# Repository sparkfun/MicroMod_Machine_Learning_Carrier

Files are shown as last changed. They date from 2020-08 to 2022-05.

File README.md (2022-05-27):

SparkFun MicroMod Machine Learning Carrier Board
========================================

SparkFun MicroMod Machine Learning Carrier Board

[*SparkFun MicroMod Machine Learning Carrier Board (16400)*](https://www.sparkfun.com/products/16400)

The MicroMod Machine Learning Carrier Board combines some of the features of our SparkFun Edge Board and SparkFun Artemis boards, but allows you the freedom to explore with any processor in the MicroMod lineup without the need for a central computer or web connection. Voice recognition, always-on voice commands, gesture, or image recognition are possible with TensorFlow applications. The cloud is impressively powerful but all-the-time connection requires power and connectivity that may not be available. Edge computing handles discrete tasks such as determining if someone said "yes" and responds accordingly. The audio analysis is done on the MicroMod combination rather than on the web. This dramatically reduces costs and complexity while limiting potential data privacy leaks. 

This board features two MEMS microphones with an operational amplifier, an ST LIS2DH12 3-axis accelerometer on its own I<sup>2</sup>C bus, a connector to interface to an OV7670 camera (sold separately), and Qwiic connector. A modern USB-C connector makes programming easy and we've exposed the JTAG connector for more advanced users who prefer to use the power and speed of professional tools. We've even added a convenient jumper to measure current consumption for low power testing.

Repository Contents
-------------------

* **/Documentation** - Data sheets, additional product information
* **/Hardware** - Eagle design files (.brd, .sch)
* **/Libraries** - Libraries for use with the <PRODUCT NAME>

Documentation
--------------
* **[Hookup Guide](https://learn.sparkfun.com/tutorials/micromod-machine-learning-carrier-board-hookup-guide)** - Basic hookup guide for the SparkFun MicroMod Machine Learning Carrier Board.
* **[Getting Started with MicroMod](https://learn.sparkfun.com/tutorials/getting-started-with-micromod)** - A tutorial to help you get started with the MicroMod Ecosystem. 
* **[Designing with MicroMod](https://learn.sparkfun.com/tutorials/designing-with-micromod)** - A tutorial to walk you through the specs of the MicroMod processor and carrier board as well as the basics of incorporating the MicroMod form factor into your own PCB designs.

License Information
-------------------

This product is _**open source**_! 

Please review the LICENSE.md file for license information. 

If you have any questions or concerns on licensing, please contact technical support on our [SparkFun forums](https://forum.sparkfun.com/viewforum.php?f=152).

Distributed as-is; no warranty is given.

- Your friends at SparkFun.

_<COLLABORATION CREDIT>_

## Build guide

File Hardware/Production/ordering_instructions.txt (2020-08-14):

panel size, 139x165mm
PCB thickness, 1.6mm
number of layers, 2
soldermask color, Red
silkscreen color, White
oz copper, 1oz
finish, HASL lead free
stencils, none
pcs per panel, 6
min trace width, 0.1778mm / 0.0070in
min drill size, 0.3048mm / 0.0120in

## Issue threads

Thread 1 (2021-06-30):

Example1_MicrophoneOutput compile error

johncaipa, 2021-06-30:
Hi I am trying to test this example of the microphone, but I have the following error:

> Arduino:1.8.13 (Windows 10), Tarjeta:"SparkFun MicroMod nRF52840 Processor Board"
Example1_MicrophoneOutput:24:1: error: 'AP3_PDM' does not name a type; did you mean 'NRF_PDM'?
 AP3_PDM myPDM;   //Create instance of PDM class
 ^~~~~~~
 NRF_PDM
D:MicroMod_Machine_Learning_Carrier-master\Examples\Example1_MicrophoneOutput\Example1_MicrophoneOutput.ino: In function 'void setup()':
Example1_MicrophoneOutput:35:7: error: 'myPDM' was not declared in this scope
   if (myPDM.begin(36, 37) == false) // Turn on PDM with default settings, start interrupts
       ^~~~~
D:MicroMod_Machine_Learning_Carrier-master\Examples\Example1_MicrophoneOutput\Example1_MicrophoneOutput.ino:35:7: note: suggested alternative: 'PDM'
   if (myPDM.begin(36, 37) == false) // Turn on PDM with default settings, start interrupts
       ^~~~~
       PDM
D:MicroMod_Machine_Learning_Carrier-master\Examples\Example1_MicrophoneOutput\Example1_MicrophoneOutput.ino: In function 'void loop()':
Example1_MicrophoneOutput:48:7: error: 'myPDM' was not declared in this scope
   if (myPDM.available())
       ^~~~~
D:MicroMod_Machine_Learning_Carrier-master\Examples\Example1_MicrophoneOutput\Example1_MicrophoneOutput.ino:48:7: note: suggested alternative: 'PDM'
   if (myPDM.available())
       ^~~~~
       PDM
Example1_MicrophoneOutput:56:24: error: 'AM_HAL_SYSCTRL_SLEEP_DEEP' was not declared in this scope
   am_hal_sysctrl_sleep(AM_HAL_SYSCTRL_SLEEP_DEEP);
                        ^~~~~~~~~~~~~~~~~~~~~~~~~
Example1_MicrophoneOutput:56:3: error: 'am_hal_sysctrl_sleep' was not declared in this scope
   am_hal_sysctrl_sleep(AM_HAL_SYSCTRL_SLEEP_DEEP);
   ^~~~~~~~~~~~~~~~~~~~
D:MicroMod_Machine_Learning_Carrier-master\Examples\Example1_MicrophoneOutput\Example1_MicrophoneOutput.ino: In function 'void printPDMConfig()':
Example1_MicrophoneOutput:139:11: error: 'myPDM' was not declared in this scope
   switch (myPDM.getClockDivider())
           ^~~~~
....

exit status 1
'AP3_PDM' does not name a type; did you mean 'NRF_PDM'?

johncaipa, 2021-06-30:
Could you help me, I don't know what the problem is, I want to be able to use the microphone for my tinyml models

santaimpersonator, 2021-07-01:
It looks like you have the nRF processor board selected.

The example explicitly states that it is intended for the Artemis processor board:
>[This example demonstrates how to use the pulse density microphone (PDM) on Artemis boards.
> This library and example are heavily based on the Apollo3 pdm_fft example.](https://github.com/sparkfun/MicroMod_Machine_Learning_Carrier/blob/master/Examples/Example1_MicrophoneOutput/Example1_MicrophoneOutput.ino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)

johncaipa, 2021-07-01:
ok I understand, my mistake, but could there be some examples of how to use the sensors of these boards:  MicroMod nRF52840 Processor Board + MicroMod Machine Learning Board, especially to use the microphone.

santaimpersonator, 2021-07-01:
Unfortunately, the nRF processor board was released after the ML carrier board. Therefore, I don't know if any of the examples associated with this carrier board will work for that MicroMod combination.

However, there was an edge impulse workshop from yesterday that might be helpful to you: https://www.youtube.com/watch?v=qdzPTzL7ChI

Since this is not an actual issue with the board, I am going to close this issue. Feel free to use [our forum for further technical assistance](https://forum.sparkfun.com/).

Closed 2021-07-01.

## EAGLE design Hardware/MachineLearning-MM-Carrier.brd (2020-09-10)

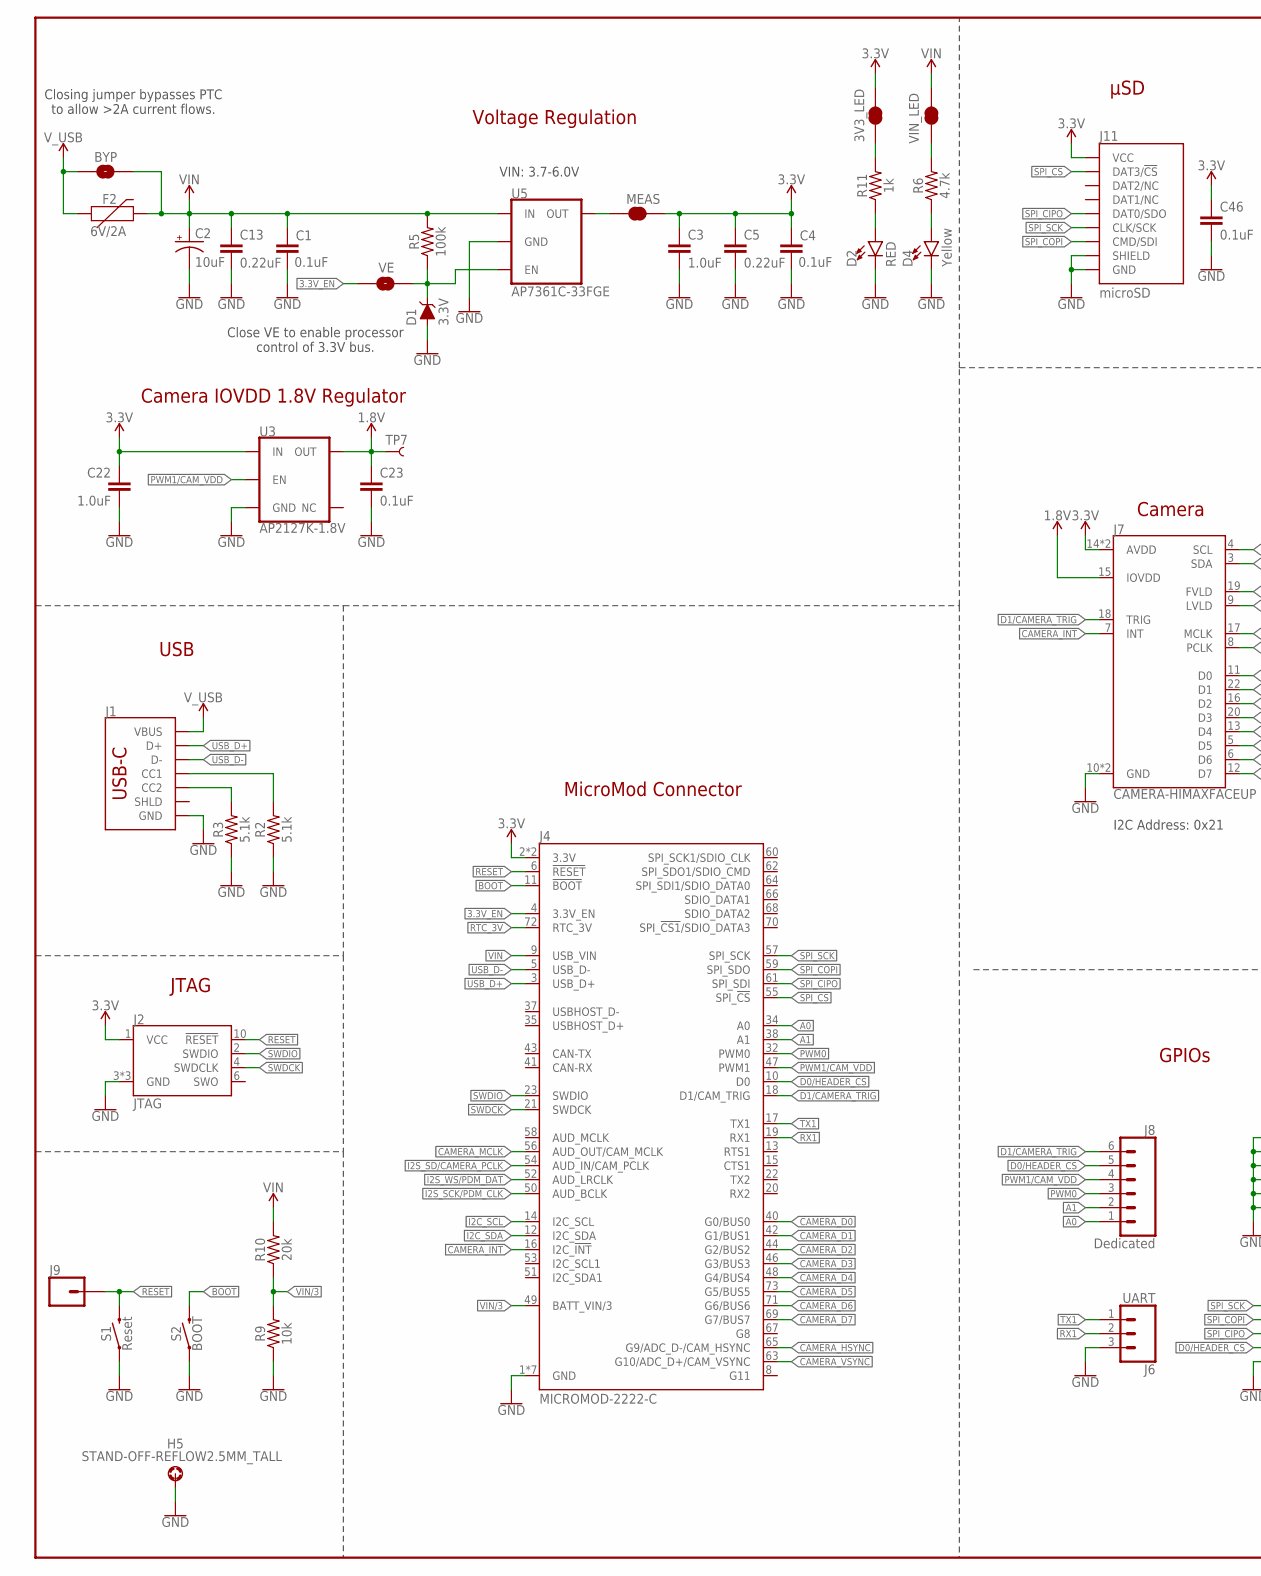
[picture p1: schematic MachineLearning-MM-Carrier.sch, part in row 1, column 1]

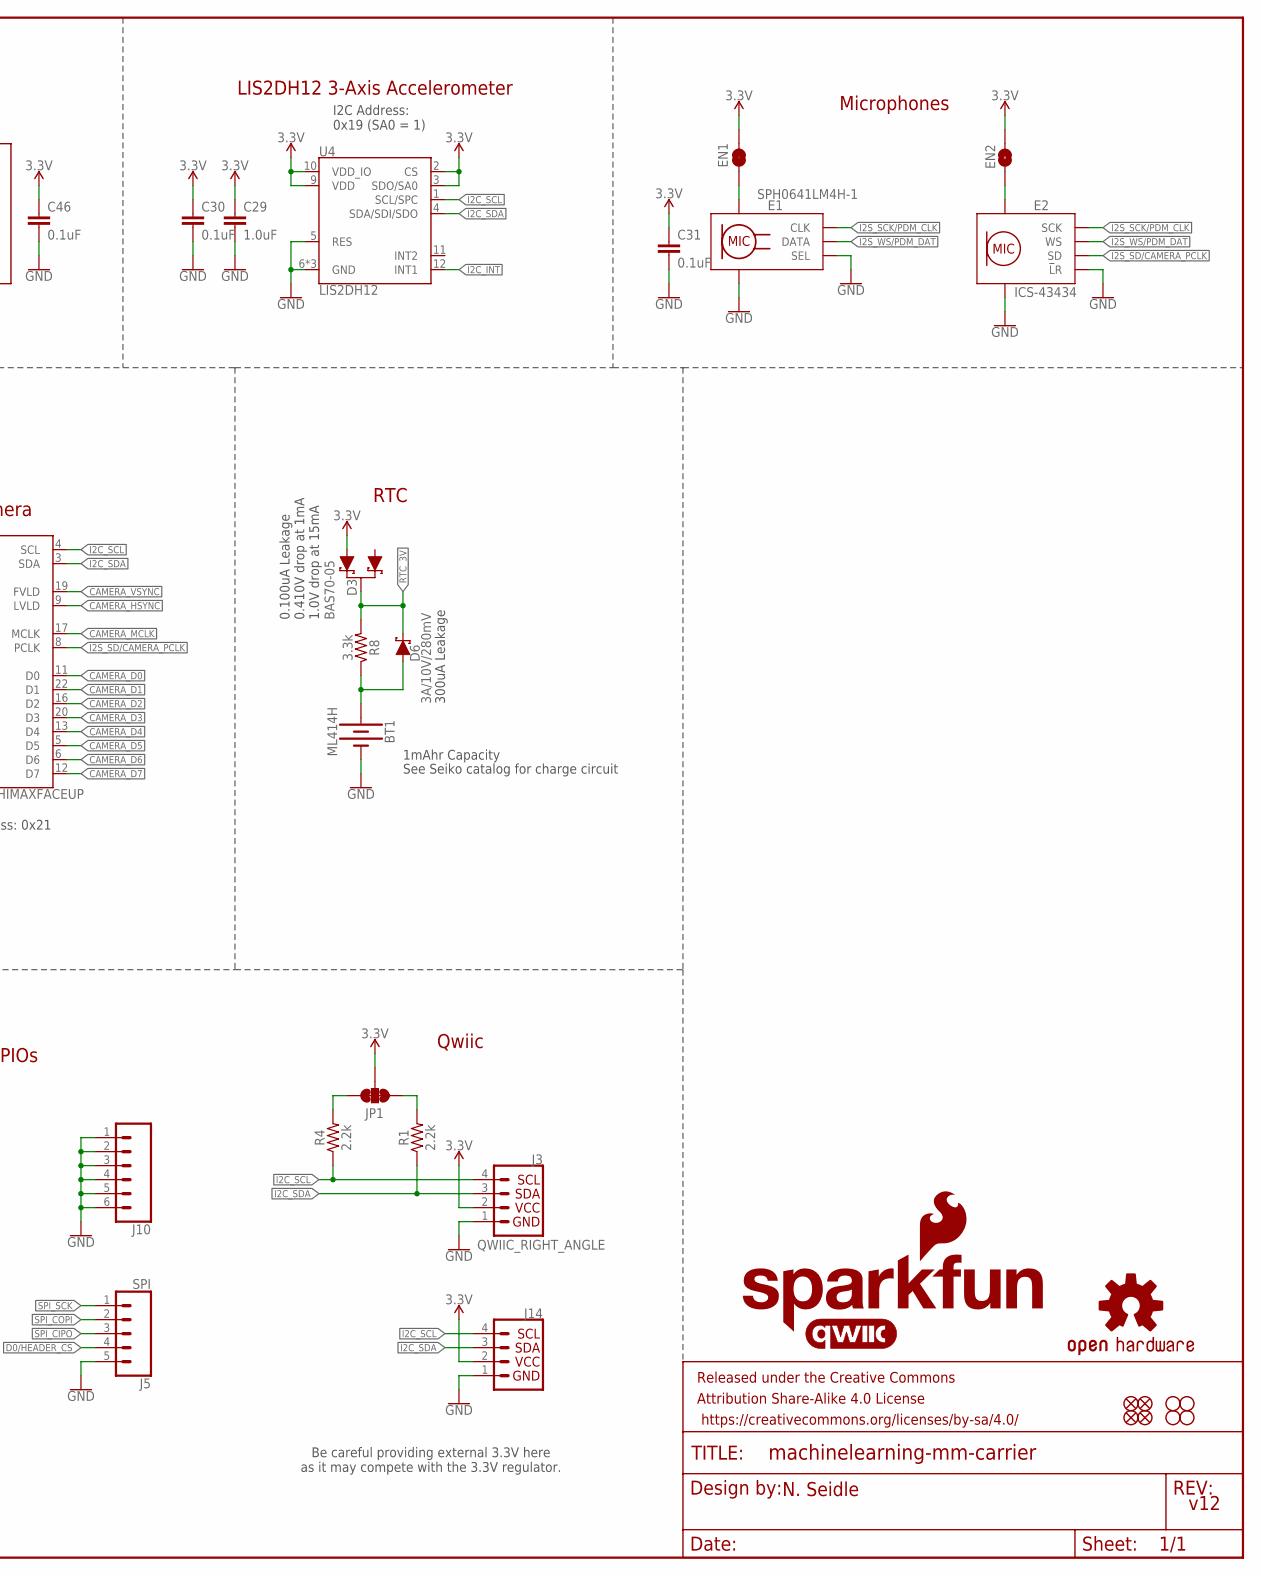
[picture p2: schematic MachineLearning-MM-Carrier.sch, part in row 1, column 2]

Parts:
3V3_LED: JUMPER-SMT_2_NC_TRACE_SILK; SMT-JUMPER_2_NC_TRACE_SILK
BT1: ML414H; ML414H_IV01E
BYP: JUMPER-SMT_2_NO_SILK; SMT-JUMPER_2_NO_SILK
C1, C4, C23, C30, C31, C46: 0.1uF; 0603
C2: 10uF; EIA3216
C3, C22, C29: 1.0uF; 0603
C5, C13: 0.22uF; 0603
D1: 3.3V; SOD-323
D2: RED; LED-0603
D3: BAS70-05; SOT23-3
D4: Yellow; LED-0603
D6: 3A/10V/280mV; SOD-323
E1: SPH0641LM4H-1; SPH0641LM4H-1_MICROPHONE
E2: ICS-43434
EN1: JUMPER-SMT_2_NC_TRACE_SILK; SMT-JUMPER_2_NC_TRACE_SILK
EN2: JUMPER-SMT_2_NO_SILK; SMT-JUMPER_2_NO_SILK
F2: 6V/2A; 1210
FD1, FD2, FD3, FD4: FIDUCIALUFIDUCIAL; FIDUCIAL-MICRO
FRAME1: FRAME-LEDGER; CREATIVE_COMMONS
H1, H2, H3, H4: STAND-OFF
H5: STAND-OFF-REFLOW2.5MM_TALL; STAND-OFF-REFLOW-M2.5
J1: USB_C_2-LAYER_PADS; USB-C-16P-2LAYER-PADS
J2: JTAG; 2X5-PTH-1.27MM
J3: QWIIC_RIGHT_ANGLE; JST04_1MM_RA
J4: MICROMOD-2222-C; M.2-CONNECTOR-E
J5: SPI; 1X05_NO_SILK
J6: UART; 1X03_NO_SILK
J7: CAMERA-HIMAXFACEUP; FPC05024-42201
J8: Dedicated; 1X06_NO_SILK
J9: CONN_01PTH_NO_SILK_YES_STOP; 1X01_NO_SILK
J10: CONN_06NO_SILK_NO_POP; 1X06_NO_SILK
J11: microSD; MICRO-SD-SOCKET
J14: I2C_STANDARD_NO_SILK; 1X04_NO_SILK
JP1: JUMPER-SMT_3_2-NC_TRACE_SILK; SMT-JUMPER_3_2-NC_TRACE_SILK
LOGO1: SFE_LOGO_NAME_FLAME.1_INCH; SFE_LOGO_NAME_FLAME_.1
LOGO2: QWIIC_LOGO_CONNECTOR; QWIIC_5.5MM
LOGO3: OSHW-LOGOMINI; OSHW-LOGO-MINI
MEAS: JUMPER-COMBO_2_NC_TRACE; COMBO-JUMPER_2_NC_TRACE
R1, R4: 2.2k; 0603
R2, R3: 5.1k; 0603
R5: 100k; 0603
R6: 4.7k; 0603
R8: 3.3k; 0603
R9: 10k; 0603
R10: 20k; 0603
R11: 1k; 0603
S1: Reset; TACTILE_SWITCH_SMD_5.2MM
S2: BOOT; TACTILE_SWITCH_SMD_5.2MM
TP7: TEST-POINT3X5; PAD.03X.05
U3: AP2127K-1.8V; SOT23-5
U4: LIS2DH12; LGA-12-LISDH12
U5: AP7361C-33FGE; UDFN-8
VE: JUMPER-SMT_2_NO_SILK; SMT-JUMPER_2_NO_SILK
VIN_LED: JUMPER-SMT_2_NC_TRACE_SILK; SMT-JUMPER_2_NC_TRACE_SILK

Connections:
1.8V: C23.1, J7.15 (IOVDD), TP7.P$1, U3.5 (OUT)
3.3V: 3V3_LED.2, C3.1, C4.1, C5.1, C22.1, C29.1, C30.1, C31.1, C46.1, D3.2 (A1), EN1.2, EN2.2, J2.1 (VCC), J3.2, J4.2 (3.3V), J4.74 (3.3V), J7.14 (AVDD), J7.21 (AVDD), J11.VCC, J14.2, JP1.2, MEAS.2, MEAS.4 (2), U3.1 (IN), U4.2 (CS), U4.3 (SDO/SA0), U4.9 (VDD), U4.10 (VDD_IO)
3.3V_EN: J4.4 (3.3V_EN), VE.1
!BOOT!: J4.11 (!BOOT!), S2.3 (2), S2.4 (2)
!RESET!: J2.10 (!RESET), J4.6 (!RESET!), J9.1, S1.3 (2), S1.4 (2)
A0: J4.34 (A0), J8.1
A1: J4.38 (A1), J8.2
CAMERA_D0: J4.40 (G0/BUS0), J7.11 (D0)
CAMERA_D1: J4.42 (G1/BUS1), J7.22 (D1)
CAMERA_D2: J4.44 (G2/BUS2), J7.16 (D2)
CAMERA_D3: J4.46 (G3/BUS3), J7.20 (D3)
CAMERA_D4: J4.48 (G4/BUS4), J7.13 (D4)
CAMERA_D5: J4.73 (G5/BUS5), J7.5 (D5)
CAMERA_D6: J4.71 (G6/BUS6), J7.6 (D6)
CAMERA_D7: J4.69 (G7/BUS7), J7.12 (D7)
CAMERA_HSYNC: J4.65 (G9/ADC_D-/CAM_HSYNC), J7.9 (LVLD)
CAMERA_INT: J4.16 (I2C_!INT!), J7.7 (INT)
CAMERA_MCLK: J4.56 (AUD_OUT/CAM_MCLK), J7.17 (MCLK)
CAMERA_VSYNC: J4.63 (G10/ADC_D+/CAM_VSYNC), J7.19 (FVLD)
D0/HEADER_!CS!: J4.10 (D0), J5.4, J8.5
D1/CAMERA_TRIG: J4.18 (D1/CAM_TRIG), J7.18 (TRIG), J8.6
GND: BT1.-, C1.2, C2.-, C3.2, C4.2, C5.2, C13.2, C22.2, C23.2, C29.2, C30.2, C31.2, C46.2, D1.A, D2.C, D4.C, E1.2 (SEL), E1.3 (GND), E1.6 (GND), E1.7 (GND), E1.8 (GND), E2.2 (!L!R), E2.3 (GND), E2.7 (GND), E2.8 (GND), E2.9 (GND), H5.1, J1.GND, J1.GND2 (GND), J2.3 (GND), J2.5 (GND), J2.9 (GND), J3.1, J4.1 (GND), J4.7 (GND), J4.33 (GND), J4.36 (GND), J4.39 (GND), J4.45 (GND), J4.75 (GND), J5.5, J6.3, J7.10 (GND), J7.23 (GND), J10.1, J10.2, J10.3, J10.4, J10.5, J10.6, J11.CD1 (SHIELD), J11.GND, J11.GND1 (GND), J11.GND3 (GND), J14.1, R2.1, R3.1, R9.1, S1.1, S1.2 (1), S2.1, S2.2 (1), U3.2 (GND), U4.5 (RES), U4.6 (GND), U4.7 (GND), U4.8 (GND), U5.4 (GND), U5.EP (GND)
I2C_!INT!: U4.12 (INT1)
I2C_SCL: J3.4, J4.14 (I2C_SCL), J7.4 (SCL), J14.4, R4.1, U4.1 (SCL/SPC)
I2C_SDA: J3.3, J4.12 (I2C_SDA), J7.3 (SDA), J14.3, R1.1, U4.4 (SDA/SDI/SDO)
I2S_SCK/PDM_CLK: E1.4 (CLK), E2.4 (SCK), J4.50 (AUD_BCLK)
I2S_SD/CAMERA_PCLK: E2.6 (SD), J4.54 (AUD_IN/CAM_PCLK), J7.8 (PCLK)
I2S_WS/PDM_DAT: E1.1 (DATA), E2.1 (WS), J4.52 (AUD_LRCLK)
unnamed: R6.2, VIN_LED.1
unnamed: JP1.3, R4.2
unnamed: JP1.1, R1.2
unnamed: E1.5 (VDD), EN1.1
unnamed: E2.5 (VDD), EN2.1
unnamed: 3V3_LED.1, R11.2
unnamed: D2.A, R11.1
unnamed: D4.A, R6.1
unnamed: J1.A5 (CC1), R2.2
unnamed: J1.B5 (CC2), R3.2
unnamed: D1.C, R5.1, U5.5 (EN), VE.2
unnamed: BT1.+, D6.A, R8.1
PWM0: J4.32 (PWM0), J8.3
PWM1/CAM_VDD: J4.47 (PWM1), J8.4, U3.3 (EN)
RTC_3V: D3.3 (C), D6.C, J4.72 (RTC_3V), R8.2
RX1: J4.19 (RX1), J6.2
SPI_!CS!: J4.55 (SPI_!CS!), J11.CS/DAT3 (DAT3/!CS!)
SPI_CIPO: J4.61 (SPI_SDI), J5.3, J11.DO/DAT0 (DAT0/SDO)
SPI_COPI: J4.59 (SPI_SDO), J5.2, J11.DI/CMD (CMD/SDI)
SPI_SCK: J4.57 (SPI_SCK), J5.1, J11.SCLK (CLK/SCK)
SWDCK: J2.4 (SWDCLK), J4.21 (SWDCK)
SWDIO: J2.2 (SWDIO), J4.23 (SWDIO)
TX1: J4.17 (TX1), J6.1
USB_D+: J1.A6 (D+), J1.B6 (D+), J4.3 (USB_D+)
USB_D-: J1.A7 (D-), J1.B7 (D-), J4.5 (USB_D-)
VIN: BYP.2, C1.1, C2.+, C13.1, F2.2, J4.9 (USB_VIN), R5.2, R10.2, U5.8 (IN), VIN_LED.2
VIN/3: J4.49 (BATT_VIN/3), R9.2, R10.1
VREG_3.3V: MEAS.1, MEAS.3 (1), U5.1 (OUT)
V_USB: BYP.1, F2.1, J1.VBUS1 (VBUS), J1.VBUS2 (VBUS)

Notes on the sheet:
LIS2DH12 3-Axis Accelerometer
I2C Address: 0x19 (SA0 = 1)
I2C Address: 0x21
μSD
300uA Leakage
See Seiko catalog for charge circuit
1mAhr Capacity
Closing jumper bypasses PTC to allow >2A current flows.
JTAG
Camera IOVDD 1.8V Regulator
USB
GPIOs
Camera
Microphones
Qwiic
RTC
Voltage Regulation
MicroMod Connector
0.100uA Leakage 0.410V drop at 1mA 1.0V drop at 15mA
N. Seidle
v12
VIN: 3.7-6.0V
Be careful providing external 3.3V here as it may compete with the 3.3V regulator.
Close VE to enable processor control of 3.3V bus.

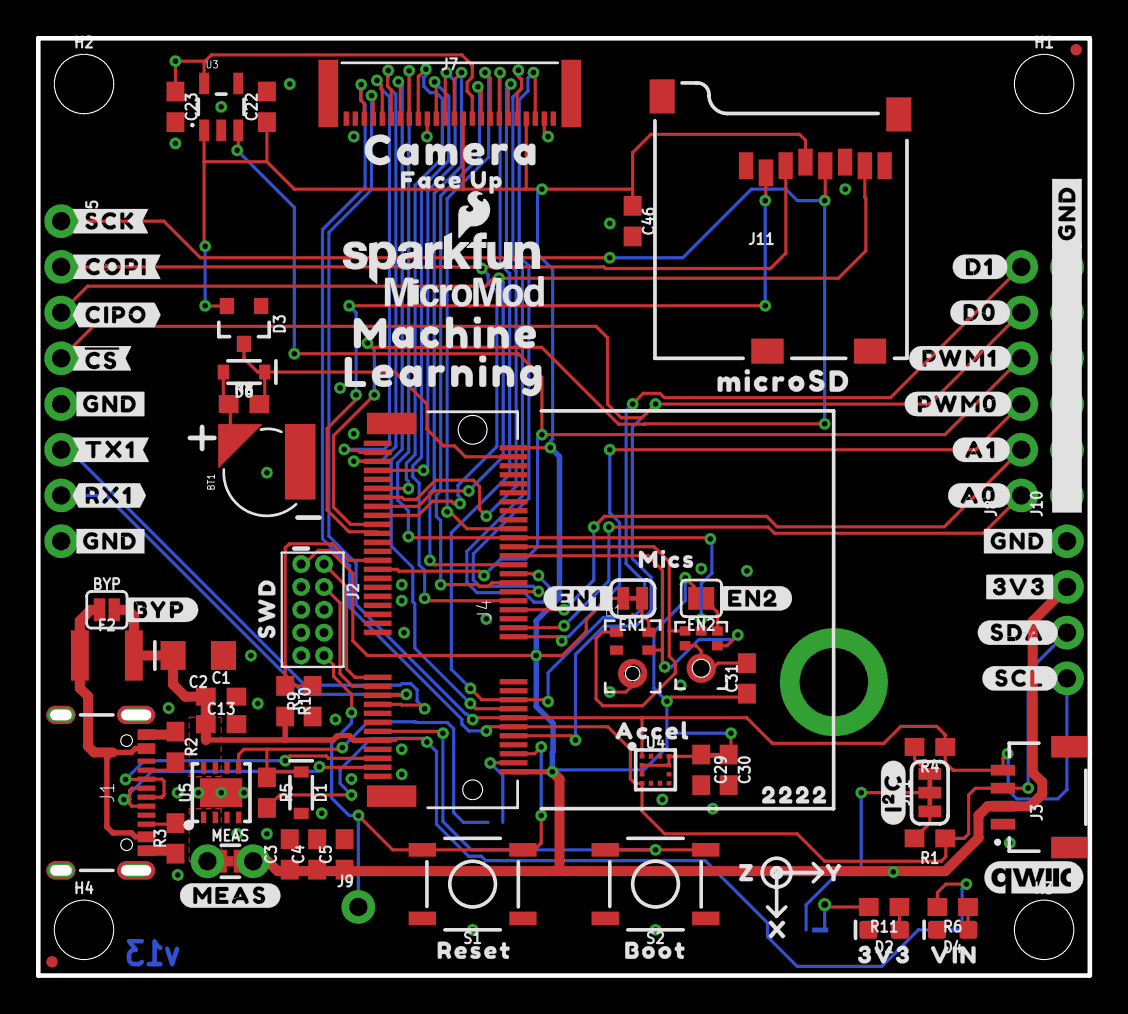
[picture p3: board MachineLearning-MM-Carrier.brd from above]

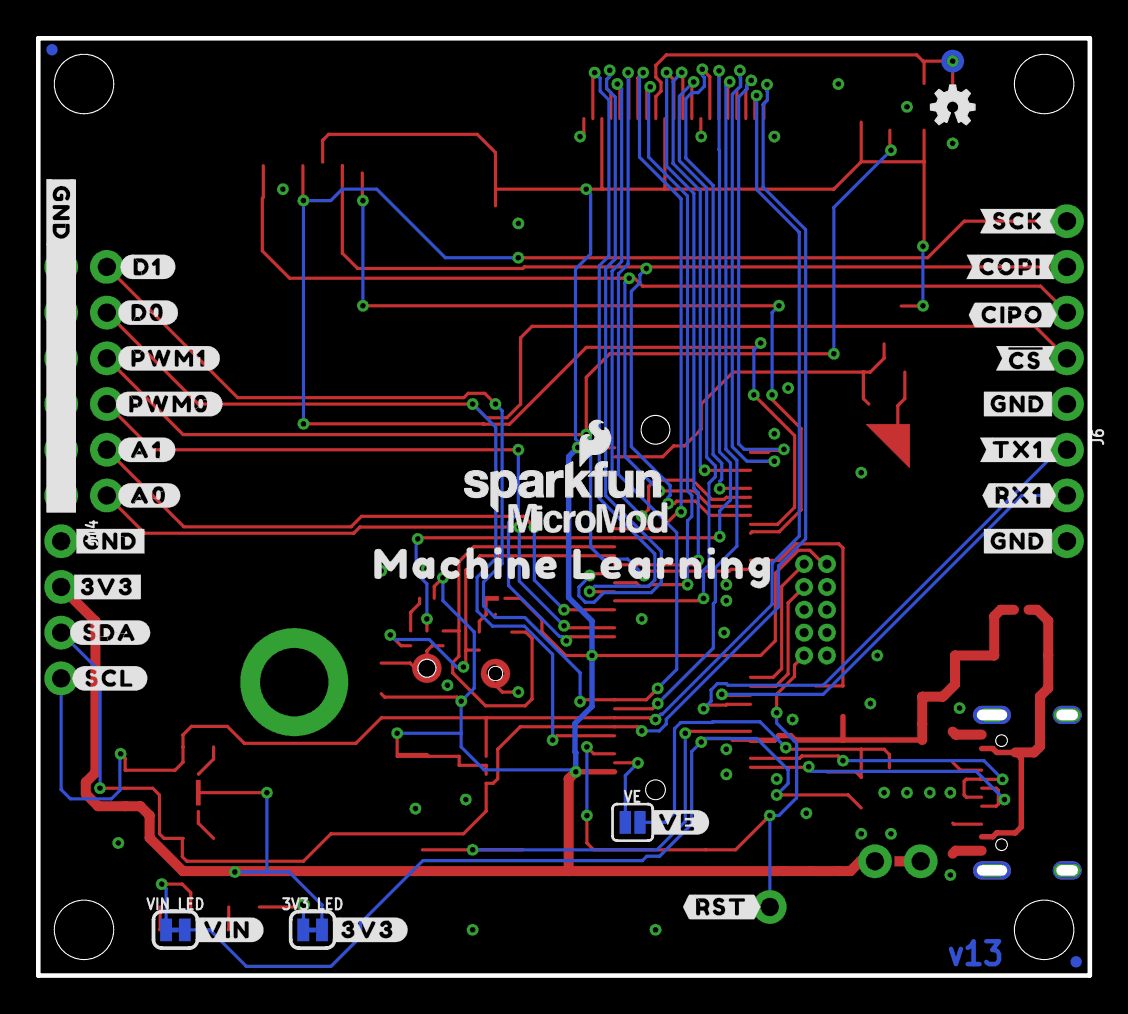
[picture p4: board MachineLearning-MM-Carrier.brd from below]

Board: 2 copper layers, 58.4 x 52.1 mm, 138 parts (36 on the bottom side), 56 nets.

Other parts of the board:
LOGO4: SFE_LOGO_NAME_FLAME.1_INCH; SFE_LOGO_NAME_FLAME_.1
U$1: #EN1#3
U$2: #EN2#4
U$3: CAMERA0
U$4: #3V3#0
U$5: MICS0
U$6, U$7: #A0#5
U$8, U$9: #A1#4
U$10, U$25: #D0#1
U$11, U$12, U$15, U$16: #GND#0
U$13, U$14: #3V3#1
U$17: #RST#1
U$18: #VE#0
U$19: #MEAS#2
U$20: #VIN#1
U$21: SWD0
U$22: FACE_UP0
U$23: #I�C#0
U$24, U$34: MICROMOD_LOGO_.35
U$26, U$37: MACHINE0
U$27, U$30: LEARNING1
U$28: MICROSD0
U$29, U$31: #D1#0
U$32, U$41: #PWM0#3
U$33: #BYP#1
U$35, U$68: ##CS##3
U$36: 3V37
U$38: 22223
U$39: ACCEL4
U$40: BOOT5
U$42, U$49: #PWM1#2
U$43, U$44: #SCL#3
U$45: RESET6
U$46: VIN8
U$47: X1
U$48: Y2
U$50, U$51: #SDA#2
U$52: Z0
U$69, U$70: #CIPO#2
U$71, U$72: #COPI#1
U$73, U$74, U$81, U$82: #GND#4
U$75, U$76: #RX1#6
U$77, U$78: #SCK#0
U$79, U$80: #TX1#5

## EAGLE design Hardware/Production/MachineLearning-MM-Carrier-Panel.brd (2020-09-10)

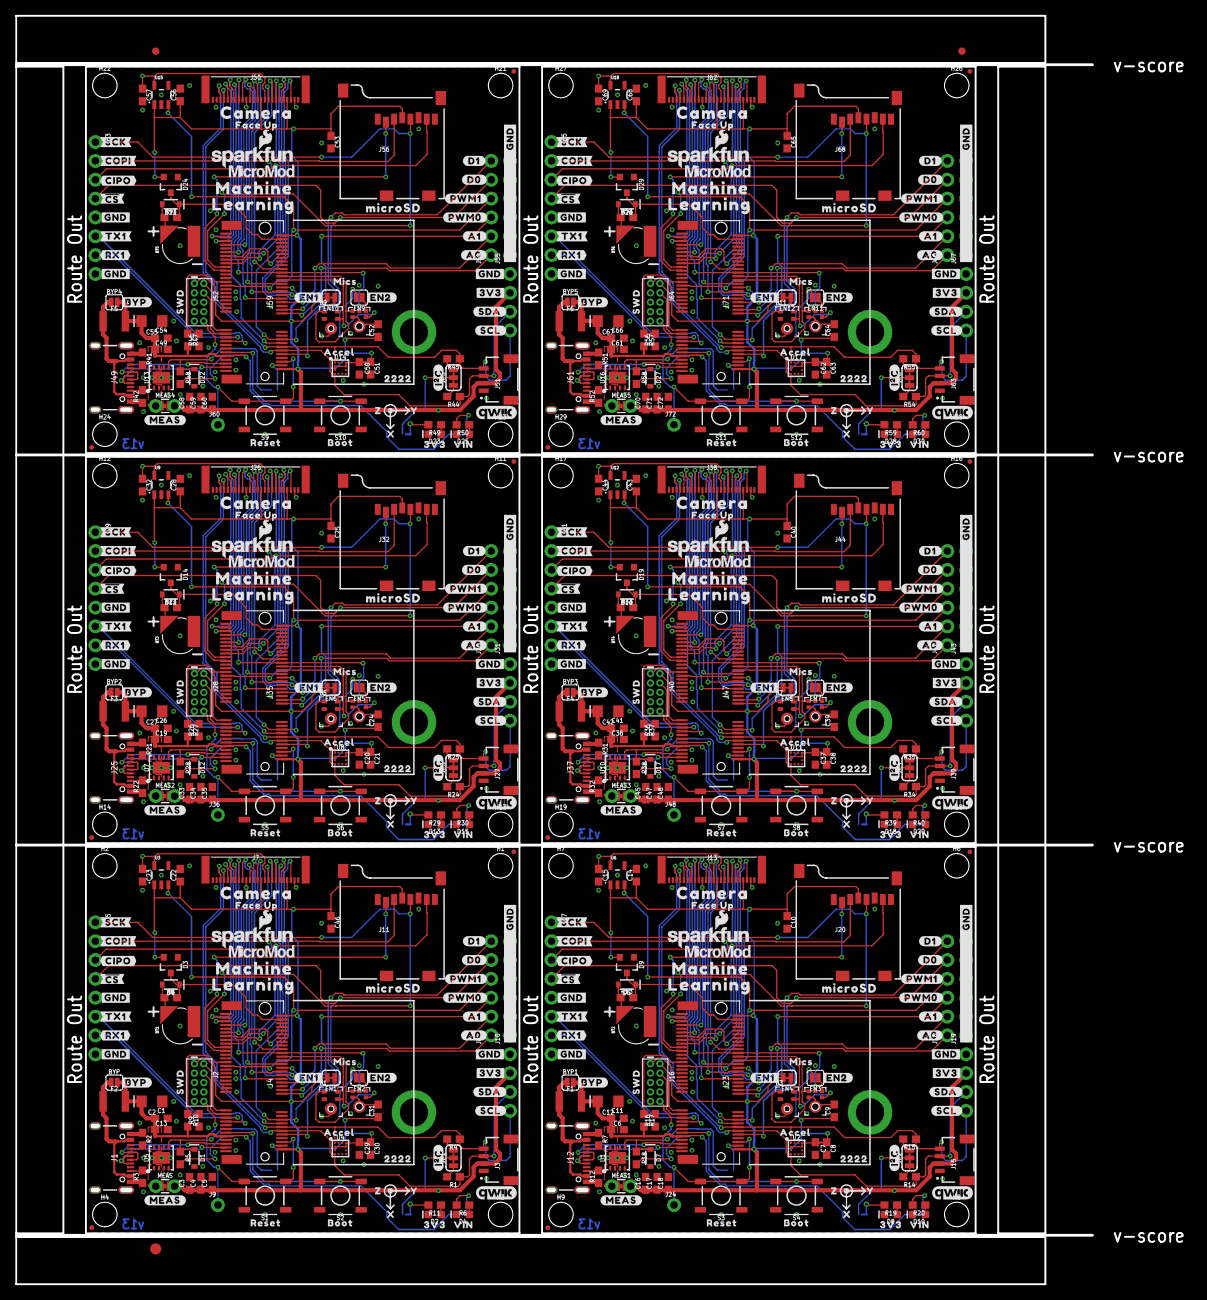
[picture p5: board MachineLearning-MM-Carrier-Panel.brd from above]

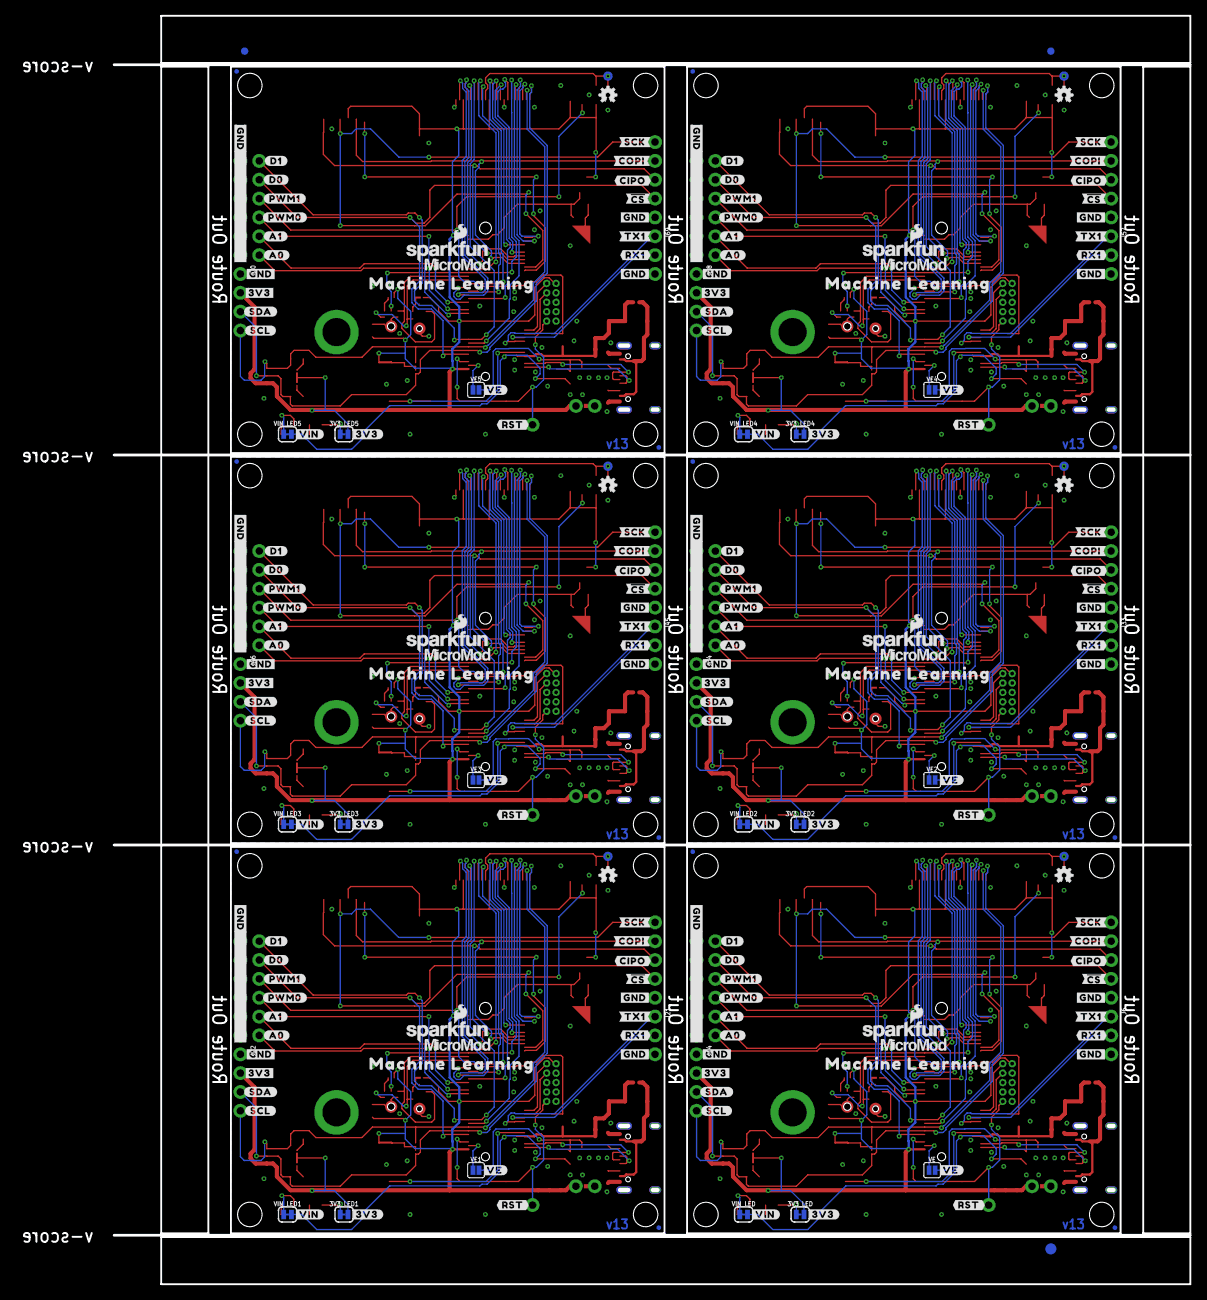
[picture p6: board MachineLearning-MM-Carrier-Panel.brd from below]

Board: 2 copper layers, 145.0 x 170.9 mm, 828 parts (219 on the bottom side), 336 nets.

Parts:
3V3_LED, 3V3_LED1, 3V3_LED2, 3V3_LED3, 3V3_LED4, 3V3_LED5: SMT-JUMPER_2_NC_TRACE_SILK
BT1, BT2, BT3, BT4, BT5, BT6: ML414H; ML414H_IV01E
BYP, BYP1, BYP2, BYP3, BYP4, BYP5: JUMPER-SMT_2_NO_SILK; SMT-JUMPER_2_NO_SILK
C1, C4, C8, C9, C10, C11, C15, C17, C21, C23, C24, C25, C26, C30, C31, C32, C34, C38, C39, C40, C41, C44, C46, C47, C51, C52, C53, C54, C57, C59, C63, C64, C65, C66, C69, C71: 0.1uF; 0603
C2, C12, C27, C42, C55, C67: 10uF; EIA3216
C3, C7, C14, C16, C20, C22, C28, C29, C33, C37, C43, C45, C50, C56, C58, C62, C68, C70: 1.0uF; 0603
C5, C6, C13, C18, C19, C35, C36, C48, C49, C60, C61, C72: 0.22uF; 0603
D1, D7, D12, D17, D22, D27: 3.3V; SOD-323
D2, D8, D13, D18, D23, D28: RED; LED-0603
D3, D9, D14, D19, D24, D29: BAS70-05; SOT23-3
D4, D10, D15, D20, D25, D30: Yellow; LED-0603
D5, D6, D11, D16, D21, D26: 3A/10V/280mV; SOD-323
E1, E3, E5, E7, E9, E11: SPH0641LM4H-1; SPH0641LM4H-1_MICROPHONE
E2, E4, E6, E8, E10, E12: ICS-43434
E$1, E$2, E$3, E$4: FIDUCIAL-1X2
E$5, E$6: FIDUCIAL-1.5X3
EN1, EN4, EN6, EN8, EN10, EN12: SMT-JUMPER_2_NC_TRACE_SILK
EN2, EN3, EN5, EN7, EN9, EN11: SMT-JUMPER_2_NO_SILK
F1, F2, F3, F4, F5, F6: 6V/2A; 1210
FD1, FD2, FD3, FD4, FD5, FD6, FD7, FD8, FD9, FD10, FD11, FD12, FD13, FD14, FD15, FD16, FD17, FD18, FD19, FD20, FD21, FD22, FD23, FD24: FIDUCIALUFIDUCIAL; FIDUCIAL-MICRO
H1, H2, H3, H4, H6, H7, H8, H9, H11, H12, H13, H14, H16, H17, H18, H19, H21, H22, H23, H24, H26, H27, H28, H29: STAND-OFF
H5, H10, H15, H20, H25, H30: STAND-OFF-REFLOW2.5MM_TALL; STAND-OFF-REFLOW-M2.5
J1, J12, J25, J37, J49, J61: USB-C-16P-2LAYER-PADS
J2, J16, J28, J40, J52, J64: JTAG; 2X5-PTH-1.27MM
J3, J15, J27, J39, J51, J63: QWIIC_RIGHT_ANGLE; JST04_1MM_RA
J4, J23, J35, J47, J59, J71: MICROMOD-2222-C; M.2-CONNECTOR-E
J5, J17, J29, J41, J53, J65: SPI; 1X05_NO_SILK
J6, J21, J33, J45, J57, J69: UART; 1X03_NO_SILK
J7, J13, J26, J38, J50, J62: CAMERA-HIMAXFACEUP; FPC05024-42201
J8, J18, J30, J42, J54, J66: Dedicated; 1X06_NO_SILK
J9, J24, J36, J48, J60, J72: 1X01_NO_SILK
J10, J19, J31, J43, J55, J67: 1X06_NO_SILK
J11, J20, J32, J44, J56, J68: microSD; MICRO-SD-SOCKET
J14, J22, J34, J46, J58, J70: 1X04_NO_SILK
JP1, JP2, JP3, JP4, JP5, JP6: SMT-JUMPER_3_2-NC_TRACE_SILK
LOGO1, LOGO4, LOGO5, LOGO8, LOGO9, LOGO12, LOGO13, LOGO16, LOGO17, LOGO20, LOGO21, LOGO24: SFE_LOGO_NAME_FLAME.1_INCH; SFE_LOGO_NAME_FLAME_.1
LOGO2, LOGO6, LOGO10, LOGO14, LOGO18, LOGO22: QWIIC_LOGO_CONNECTOR; QWIIC_5.5MM
LOGO3, LOGO7, LOGO11, LOGO15, LOGO19, LOGO23: OSHW-LOGOMINI; OSHW-LOGO-MINI
MEAS, MEAS1, MEAS2, MEAS3, MEAS4, MEAS5: COMBO-JUMPER_2_NC_TRACE
R1, R4, R14, R15, R24, R25, R34, R35, R44, R45, R54, R55: 2.2k; 0603
R2, R3, R7, R12, R21, R22, R31, R32, R41, R42, R51, R52: 5.1k; 0603
R5, R18, R28, R38, R48, R58: 100k; 0603
R6, R20, R30, R40, R50, R60: 4.7k; 0603
R8, R13, R23, R33, R43, R53: 3.3k; 0603
R9, R16, R26, R36, R46, R56: 10k; 0603
R10, R17, R27, R37, R47, R57: 20k; 0603
R11, R19, R29, R39, R49, R59: 1k; 0603
S1, S3, S5, S7, S9, S11: Reset; TACTILE_SWITCH_SMD_5.2MM
S2, S4, S6, S8, S10, S12: BOOT; TACTILE_SWITCH_SMD_5.2MM
TP1, TP2, TP3, TP4, TP5, TP7: TEST-POINT3X5; PAD.03X.05
U1, U5, U7, U10, U13, U16: AP7361C-33FGE; UDFN-8
U2, U4, U8, U11, U14, U17: LIS2DH12; LGA-12-LISDH12
U3, U6, U9, U12, U15, U18: AP2127K-1.8V; SOT23-5
U$1, U$117, U$184, U$251, U$318, U$385: #EN1#3
U$2, U$118, U$185, U$252, U$319, U$386: #EN2#4
U$3, U$128, U$195, U$262, U$329, U$396: CAMERA0
U$4, U$130, U$197, U$264, U$331, U$398: #3V3#0
U$5, U$122, U$189, U$256, U$323, U$390: MICS0
U$6, U$7, U$86, U$87, U$153, U$154, U$220, U$221, U$287, U$288, U$354, U$355: #A0#5
U$8, U$9, U$88, U$89, U$155, U$156, U$222, U$223, U$289, U$290, U$356, U$357: #A1#4
U$10, U$25, U$90, U$91, U$157, U$158, U$224, U$225, U$291, U$292, U$358, U$359: #D0#1
U$11, U$12, U$15, U$16, U$98, U$99, U$102, U$103, U$165, U$166, U$169, U$170, U$232, U$233, U$236, U$237, U$299, U$300, U$303, U$304, U$366, U$367, U$370, U$371: #GND#0
U$13, U$14, U$100, U$101, U$167, U$168, U$234, U$235, U$301, U$302, U$368, U$369: #3V3#1
U$17, U$123, U$190, U$257, U$324, U$391: #RST#1
U$18, U$124, U$191, U$258, U$325, U$392: #VE#0
U$19, U$119, U$186, U$253, U$320, U$387: #MEAS#2
U$20, U$131, U$198, U$265, U$332, U$399: #VIN#1
U$21, U$120, U$187, U$254, U$321, U$388: SWD0
U$22, U$129, U$196, U$263, U$330, U$397: FACE_UP0
U$23, U$125, U$192, U$259, U$326, U$393: #I�C#0
U$24, U$34, U$53, U$54, U$135, U$136, U$202, U$203, U$269, U$270, U$336, U$337: MICROMOD_LOGO_.35
U$26, U$37, U$126, U$134, U$193, U$201, U$260, U$268, U$327, U$335, U$394, U$402: MACHINE0
U$27, U$30, U$127, U$133, U$194, U$200, U$261, U$267, U$328, U$334, U$395, U$401: LEARNING1
U$28, U$132, U$199, U$266, U$333, U$400: MICROSD0
U$29, U$31, U$92, U$93, U$159, U$160, U$226, U$227, U$293, U$294, U$360, U$361: #D1#0
U$32, U$41, U$94, U$95, U$161, U$162, U$228, U$229, U$295, U$296, U$362, U$363: #PWM0#3
U$33, U$121, U$188, U$255, U$322, U$389: #BYP#1
U$35, U$55, U$56, U$68, U$137, U$138, U$204, U$205, U$271, U$272, U$338, U$339: ##CS##3
U$36, U$108, U$175, U$242, U$309, U$376: 3V37
U$38, U$109, U$176, U$243, U$310, U$377: 22223
U$39, U$110, U$177, U$244, U$311, U$378: ACCEL4
U$40, U$111, U$178, U$245, U$312, U$379: BOOT5
U$42, U$49, U$96, U$97, U$163, U$164, U$230, U$231, U$297, U$298, U$364, U$365: #PWM1#2
U$43, U$44, U$104, U$105, U$171, U$172, U$238, U$239, U$305, U$306, U$372, U$373: #SCL#3
U$45, U$112, U$179, U$246, U$313, U$380: RESET6
U$46, U$113, U$180, U$247, U$314, U$381: VIN8
U$47, U$114, U$181, U$248, U$315, U$382: X1
U$48, U$115, U$182, U$249, U$316, U$383: Y2
U$50, U$51, U$106, U$107, U$173, U$174, U$240, U$241, U$307, U$308, U$374, U$375: #SDA#2
U$52, U$116, U$183, U$250, U$317, U$384: Z0
U$57, U$58, U$69, U$70, U$139, U$140, U$206, U$207, U$273, U$274, U$340, U$341: #CIPO#2
U$59, U$60, U$71, U$72, U$141, U$142, U$208, U$209, U$275, U$276, U$342, U$343: #COPI#1
U$61, U$62, U$73, U$74, U$81, U$82, U$84, U$85, U$143, U$144, U$151, U$152, U$210, U$211, U$218, U$219, U$277, U$278, U$285, U$286, U$344, U$345, U$352, U$353: #GND#4
U$63, U$64, U$75, U$76, U$145, U$146, U$212, U$213, U$279, U$280, U$346, U$347: #RX1#6
U$65, U$66, U$77, U$78, U$147, U$148, U$214, U$215, U$281, U$282, U$348, U$349: #SCK#0
U$67, U$79, U$80, U$83, U$149, U$150, U$216, U$217, U$283, U$284, U$350, U$351: #TX1#5
VE, VE1, VE2, VE3, VE4, VE5: SMT-JUMPER_2_NO_SILK
VIN_LED, VIN_LED1, VIN_LED2, VIN_LED3, VIN_LED4, VIN_LED5: SMT-JUMPER_2_NC_TRACE_SILK

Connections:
1.8V: C23.1, J7.15, TP7.P$1, U3.5
1.8V1: C15.1, J13.15, TP1.P$1, U6.5
1.8V2: C32.1, J26.15, TP2.P$1, U9.5
1.8V3: C44.1, J38.15, TP3.P$1, U12.5
1.8V4: C57.1, J50.15, TP4.P$1, U15.5
1.8V5: C69.1, J62.15, TP5.P$1, U18.5
3.3V: 3V3_LED.2, C3.1, C4.1, C5.1, C22.1, C29.1, C30.1, C31.1, C46.1, D3.2, EN1.2, EN2.2, J2.1, J3.2, J4.2, J4.74, J7.14, J7.21, J11.VCC, J14.2, JP1.2, MEAS.2, MEAS.4, U3.1, U4.2, U4.3, U4.9, U4.10
3.3V1: 3V3_LED1.2, C7.1, C8.1, C9.1, C10.1, C14.1, C16.1, C17.1, C18.1, D9.2, EN3.2, EN4.2, J13.14, J13.21, J15.2, J16.1, J20.VCC, J22.2, J23.2, J23.74, JP2.2, MEAS1.2, MEAS1.4, U2.2, U2.3, U2.9, U2.10, U6.1
3.3V2: 3V3_LED2.2, C20.1, C21.1, C24.1, C25.1, C28.1, C33.1, C34.1, C35.1, D14.2, EN5.2, EN6.2, J26.14, J26.21, J27.2, J28.1, J32.VCC, J34.2, J35.2, J35.74, JP3.2, MEAS2.2, MEAS2.4, U8.2, U8.3, U8.9, U8.10, U9.1
3.3V3: 3V3_LED3.2, C37.1, C38.1, C39.1, C40.1, C43.1, C45.1, C47.1, C48.1, D19.2, EN7.2, EN8.2, J38.14, J38.21, J39.2, J40.1, J44.VCC, J46.2, J47.2, J47.74, JP4.2, MEAS3.2, MEAS3.4, U11.2, U11.3, U11.9, U11.10, U12.1
3.3V4: 3V3_LED4.2, C50.1, C51.1, C52.1, C53.1, C56.1, C58.1, C59.1, C60.1, D24.2, EN9.2, EN10.2, J50.14, J50.21, J51.2, J52.1, J56.VCC, J58.2, J59.2, J59.74, JP5.2, MEAS4.2, MEAS4.4, U14.2, U14.3, U14.9, U14.10, U15.1
3.3V5: 3V3_LED5.2, C62.1, C63.1, C64.1, C65.1, C68.1, C70.1, C71.1, C72.1, D29.2, EN11.2, EN12.2, J62.14, J62.21, J63.2, J64.1, J68.VCC, J70.2, J71.2, J71.74, JP6.2, MEAS5.2, MEAS5.4, U17.2, U17.3, U17.9, U17.10, U18.1
3.3V_EN: J4.4, VE.1
3.3V_EN1: J23.4, VE1.1
3.3V_EN2: J35.4, VE2.1
3.3V_EN3: J47.4, VE3.1
3.3V_EN4: J59.4, VE4.1
3.3V_EN5: J71.4, VE5.1
!BOOT!: J4.11, S2.3, S2.4
!BOOT!1: J23.11, S4.3, S4.4
!BOOT!2: J35.11, S6.3, S6.4
!BOOT!3: J47.11, S8.3, S8.4
!BOOT!4: J59.11, S10.3, S10.4
!BOOT!5: J71.11, S12.3, S12.4
!RESET!: J2.10, J4.6, J9.1, S1.3, S1.4
!RESET!1: J16.10, J23.6, J24.1, S3.3, S3.4
!RESET!2: J28.10, J35.6, J36.1, S5.3, S5.4
!RESET!3: J40.10, J47.6, J48.1, S7.3, S7.4
!RESET!4: J52.10, J59.6, J60.1, S9.3, S9.4
!RESET!5: J64.10, J71.6, J72.1, S11.3, S11.4
A0: J4.34, J8.1
A1: J4.38, J8.2
A2: J18.1, J23.34
A3: J18.2, J23.38
A4: J30.1, J35.34
A5: J30.2, J35.38
A6: J42.1, J47.34
A7: J42.2, J47.38
A8: J54.1, J59.34
A9: J54.2, J59.38
A10: J66.1, J71.34
A11: J66.2, J71.38
CAMERA_D0: J4.40, J7.11
CAMERA_D1: J4.42, J7.22
CAMERA_D2: J4.44, J7.16
CAMERA_D3: J4.46, J7.20
CAMERA_D4: J4.48, J7.13
CAMERA_D5: J4.73, J7.5
CAMERA_D6: J4.71, J7.6
CAMERA_D7: J4.69, J7.12
CAMERA_D8: J13.22, J23.42
CAMERA_D9: J13.20, J23.46
CAMERA_D10: J13.13, J23.48
CAMERA_D11: J13.5, J23.73
CAMERA_D12: J13.6, J23.71
CAMERA_D13: J13.12, J23.69
CAMERA_D14: J13.11, J23.40
CAMERA_D15: J13.16, J23.44
CAMERA_D16: J26.22, J35.42
CAMERA_D17: J26.20, J35.46
CAMERA_D18: J26.13, J35.48
CAMERA_D19: J26.5, J35.73
CAMERA_D20: J26.6, J35.71
CAMERA_D21: J26.12, J35.69
CAMERA_D22: J26.11, J35.40
CAMERA_D23: J26.16, J35.44
CAMERA_D24: J38.22, J47.42
CAMERA_D25: J38.20, J47.46
CAMERA_D26: J38.13, J47.48
CAMERA_D27: J38.5, J47.73
CAMERA_D28: J38.6, J47.71
CAMERA_D29: J38.12, J47.69
CAMERA_D30: J38.11, J47.40
CAMERA_D31: J38.16, J47.44
CAMERA_D32: J50.22, J59.42
CAMERA_D33: J50.20, J59.46
CAMERA_D34: J50.13, J59.48
CAMERA_D35: J50.5, J59.73
CAMERA_D36: J50.6, J59.71
CAMERA_D37: J50.12, J59.69
CAMERA_D38: J50.11, J59.40
CAMERA_D39: J50.16, J59.44
CAMERA_D40: J62.22, J71.42
CAMERA_D41: J62.20, J71.46
CAMERA_D42: J62.13, J71.48
CAMERA_D43: J62.5, J71.73
CAMERA_D44: J62.6, J71.71
CAMERA_D45: J62.12, J71.69
CAMERA_D46: J62.11, J71.40
CAMERA_D47: J62.16, J71.44
CAMERA_HSYNC: J4.65, J7.9
CAMERA_HSYNC1: J13.9, J23.65
CAMERA_HSYNC2: J26.9, J35.65
CAMERA_HSYNC3: J38.9, J47.65
CAMERA_HSYNC4: J50.9, J59.65
CAMERA_HSYNC5: J62.9, J71.65
CAMERA_INT: J4.16, J7.7
CAMERA_INT1: J13.7, J23.16
CAMERA_INT2: J26.7, J35.16
CAMERA_INT3: J38.7, J47.16
CAMERA_INT4: J50.7, J59.16
CAMERA_INT5: J62.7, J71.16
CAMERA_MCLK: J4.56, J7.17
CAMERA_MCLK1: J13.17, J23.56
CAMERA_MCLK2: J26.17, J35.56
CAMERA_MCLK3: J38.17, J47.56
CAMERA_MCLK4: J50.17, J59.56
CAMERA_MCLK5: J62.17, J71.56
CAMERA_VSYNC: J4.63, J7.19
CAMERA_VSYNC1: J13.19, J23.63
CAMERA_VSYNC2: J26.19, J35.63
CAMERA_VSYNC3: J38.19, J47.63
CAMERA_VSYNC4: J50.19, J59.63
CAMERA_VSYNC5: J62.19, J71.63
D0/HEADER_!CS!: J4.10, J5.4, J8.5
D0/HEADER_!CS!1: J17.4, J18.5, J23.10
D0/HEADER_!CS!2: J29.4, J30.5, J35.10
D0/HEADER_!CS!3: J41.4, J42.5, J47.10
D0/HEADER_!CS!4: J53.4, J54.5, J59.10
D0/HEADER_!CS!5: J65.4, J66.5, J71.10
D1/CAMERA_TRIG: J4.18, J7.18, J8.6
D1/CAMERA_TRIG1: J13.18, J18.6, J23.18
D1/CAMERA_TRIG2: J26.18, J30.6, J35.18
D1/CAMERA_TRIG3: J38.18, J42.6, J47.18
D1/CAMERA_TRIG4: J50.18, J54.6, J59.18
D1/CAMERA_TRIG5: J62.18, J66.6, J71.18
GND: BT1.-, C1.2, C2.-, C3.2, C4.2, C5.2, C13.2, C22.2, C23.2, C29.2, C30.2, C31.2, C46.2, D1.A, D2.C, D4.C, E1.2, E1.3, E1.6, E1.7, E1.8, E2.2, E2.3, E2.7, E2.8, E2.9, H5.1, J1.GND, J1.GND2, J2.3, J2.5, J2.9, J3.1, J4.1, J4.7, J4.33, J4.36, J4.39, J4.45, J4.75, J5.5, J6.3, J7.10, J7.23, J10.1, J10.2, J10.3, J10.4, J10.5, J10.6, J11.CD1, J11.GND, J11.GND1, J11.GND3, J14.1, R2.1, R3.1, R9.1, S1.1, S1.2, S2.1, S2.2, U3.2, U4.5, U4.6, U4.7, U4.8, U5.4, U5.EP
GND1: BT2.-, C6.2, C7.2, C8.2, C9.2, C10.2, C11.2, C12.-, C14.2, C15.2, C16.2, C17.2, C18.2, D7.A, D8.C, D10.C, E3.2, E3.3, E3.6, E3.7, E3.8, E4.2, E4.3, E4.7, E4.8, E4.9, H10.1, J12.GND, J12.GND2, J13.10, J13.23, J15.1, J16.3, J16.5, J16.9, J17.5, J19.1, J19.2, J19.3, J19.4, J19.5, J19.6, J20.CD1, J20.GND, J20.GND1, J20.GND3, J21.3, J22.1, J23.1, J23.7, J23.33, J23.36, J23.39, J23.45, J23.75, R7.1, R12.1, R16.1, S3.1, S3.2, S4.1, S4.2, U1.4, U1.EP, U2.5, U2.6, U2.7, U2.8, U6.2
GND2: BT3.-, C19.2, C20.2, C21.2, C24.2, C25.2, C26.2, C27.-, C28.2, C32.2, C33.2, C34.2, C35.2, D12.A, D13.C, D15.C, E5.2, E5.3, E5.6, E5.7, E5.8, E6.2, E6.3, E6.7, E6.8, E6.9, H15.1, J25.GND, J25.GND2, J26.10, J26.23, J27.1, J28.3, J28.5, J28.9, J29.5, J31.1, J31.2, J31.3, J31.4, J31.5, J31.6, J32.CD1, J32.GND, J32.GND1, J32.GND3, J33.3, J34.1, J35.1, J35.7, J35.33, J35.36, J35.39, J35.45, J35.75, R21.1, R22.1, R26.1, S5.1, S5.2, S6.1, S6.2, U7.4, U7.EP, U8.5, U8.6, U8.7, U8.8, U9.2
GND3: BT4.-, C36.2, C37.2, C38.2, C39.2, C40.2, C41.2, C42.-, C43.2, C44.2, C45.2, C47.2, C48.2, D17.A, D18.C, D20.C, E7.2, E7.3, E7.6, E7.7, E7.8, E8.2, E8.3, E8.7, E8.8, E8.9, H20.1, J37.GND, J37.GND2, J38.10, J38.23, J39.1, J40.3, J40.5, J40.9, J41.5, J43.1, J43.2, J43.3, J43.4, J43.5, J43.6, J44.CD1, J44.GND, J44.GND1, J44.GND3, J45.3, J46.1, J47.1, J47.7, J47.33, J47.36, J47.39, J47.45, J47.75, R31.1, R32.1, R36.1, S7.1, S7.2, S8.1, S8.2, U10.4, U10.EP, U11.5, U11.6, U11.7, U11.8, U12.2
GND4: BT5.-, C49.2, C50.2, C51.2, C52.2, C53.2, C54.2, C55.-, C56.2, C57.2, C58.2, C59.2, C60.2, D22.A, D23.C, D25.C, E9.2, E9.3, E9.6, E9.7, E9.8, E10.2, E10.3, E10.7, E10.8, E10.9, H25.1, J49.GND, J49.GND2, J50.10, J50.23, J51.1, J52.3, J52.5, J52.9, J53.5, J55.1, J55.2, J55.3, J55.4, J55.5, J55.6, J56.CD1, J56.GND, J56.GND1, J56.GND3, J57.3, J58.1, J59.1, J59.7, J59.33, J59.36, J59.39, J59.45, J59.75, R41.1, R42.1, R46.1, S9.1, S9.2, S10.1, S10.2, U13.4, U13.EP, U14.5, U14.6, U14.7, U14.8, U15.2
GND5: BT6.-, C61.2, C62.2, C63.2, C64.2, C65.2, C66.2, C67.-, C68.2, C69.2, C70.2, C71.2, C72.2, D27.A, D28.C, D30.C, E11.2, E11.3, E11.6, E11.7, E11.8, E12.2, E12.3, E12.7, E12.8, E12.9, H30.1, J61.GND, J61.GND2, J62.10, J62.23, J63.1, J64.3, J64.5, J64.9, J65.5, J67.1, J67.2, J67.3, J67.4, J67.5, J67.6, J68.CD1, J68.GND, J68.GND1, J68.GND3, J69.3, J70.1, J71.1, J71.7, J71.33, J71.36, J71.39, J71.45, J71.75, R51.1, R52.1, R56.1, S11.1, S11.2, S12.1, S12.2, U16.4, U16.EP, U17.5, U17.6, U17.7, U17.8, U18.2
I2C_SCL: J3.4, J4.14, J7.4, J14.4, R4.1, U4.1
I2C_SCL1: J13.4, J15.4, J22.4, J23.14, R15.1, U2.1
I2C_SCL2: J26.4, J27.4, J34.4, J35.14, R25.1, U8.1
I2C_SCL3: J38.4, J39.4, J46.4, J47.14, R35.1, U11.1
I2C_SCL4: J50.4, J51.4, J58.4, J59.14, R45.1, U14.1
I2C_SCL5: J62.4, J63.4, J70.4, J71.14, R55.1, U17.1
I2C_SDA: J3.3, J4.12, J7.3, J14.3, R1.1, U4.4
I2C_SDA1: J13.3, J15.3, J22.3, J23.12, R14.1, U2.4
I2C_SDA2: J26.3, J27.3, J34.3, J35.12, R24.1, U8.4
I2C_SDA3: J38.3, J39.3, J46.3, J47.12, R34.1, U11.4
I2C_SDA4: J50.3, J51.3, J58.3, J59.12, R44.1, U14.4
I2C_SDA5: J62.3, J63.3, J70.3, J71.12, R54.1, U17.4
I2S_SCK/PDM_CLK: E1.4, E2.4, J4.50
I2S_SCK/PDM_CLK1: E3.4, E4.4, J23.50
I2S_SCK/PDM_CLK2: E5.4, E6.4, J35.50
I2S_SCK/PDM_CLK3: E7.4, E8.4, J47.50
I2S_SCK/PDM_CLK4: E9.4, E10.4, J59.50
I2S_SCK/PDM_CLK5: E11.4, E12.4, J71.50
I2S_SD/CAMERA_PCLK: E2.6, J4.54, J7.8
I2S_SD/CAMERA_PCLK1: E4.6, J13.8, J23.54
I2S_SD/CAMERA_PCLK2: E6.6, J26.8, J35.54
I2S_SD/CAMERA_PCLK3: E8.6, J38.8, J47.54
I2S_SD/CAMERA_PCLK4: E10.6, J50.8, J59.54
I2S_SD/CAMERA_PCLK5: E12.6, J62.8, J71.54
I2S_WS/PDM_DAT: E1.1, E2.1, J4.52
I2S_WS/PDM_DAT1: E3.1, E4.1, J23.52
I2S_WS/PDM_DAT2: E5.1, E6.1, J35.52
I2S_WS/PDM_DAT3: E7.1, E8.1, J47.52
I2S_WS/PDM_DAT4: E9.1, E10.1, J59.52
I2S_WS/PDM_DAT5: E11.1, E12.1, J71.52
unnamed: R6.2, VIN_LED.1
unnamed: JP1.3, R4.2
unnamed: JP1.1, R1.2
unnamed: E1.5, EN1.1
unnamed: E2.5, EN2.1
unnamed: 3V3_LED.1, R11.2
unnamed: D2.A, R11.1
unnamed: D4.A, R6.1
unnamed: J12.A5, R7.2
unnamed: J1.A5, R2.2
unnamed: J1.B5, R3.2
unnamed: D1.C, R5.1, U5.5, VE.2
unnamed: J12.B5, R12.2
unnamed: BT1.+, D6.A, R8.1
unnamed: BT2.+, D5.A, R13.1
unnamed: JP2.3, R15.2
unnamed: JP2.1, R14.2
unnamed: E3.5, EN4.1
unnamed: E4.5, EN3.1
unnamed: 3V3_LED1.1, R19.2
unnamed: D8.A, R19.1
unnamed: R20.2, VIN_LED1.1
unnamed: D10.A, R20.1
unnamed: D7.C, R18.1, U1.5, VE1.2
unnamed: J25.A5, R21.2
unnamed: J25.B5, R22.2
unnamed: BT3.+, D11.A, R23.1
unnamed: JP3.3, R25.2
unnamed: JP3.1, R24.2
unnamed: E5.5, EN6.1
unnamed: E6.5, EN5.1
unnamed: 3V3_LED2.1, R29.2
unnamed: D13.A, R29.1
unnamed: R30.2, VIN_LED2.1
unnamed: D15.A, R30.1
unnamed: D12.C, R28.1, U7.5, VE2.2
unnamed: J37.A5, R31.2
unnamed: J37.B5, R32.2
unnamed: BT4.+, D16.A, R33.1
unnamed: JP4.3, R35.2
unnamed: JP4.1, R34.2
unnamed: E7.5, EN8.1
unnamed: E8.5, EN7.1
unnamed: 3V3_LED3.1, R39.2
unnamed: D18.A, R39.1
unnamed: R40.2, VIN_LED3.1
unnamed: D20.A, R40.1
unnamed: D17.C, R38.1, U10.5, VE3.2
unnamed: J49.A5, R41.2
unnamed: J49.B5, R42.2
unnamed: BT5.+, D21.A, R43.1
unnamed: JP5.3, R45.2
unnamed: JP5.1, R44.2
unnamed: E9.5, EN10.1
unnamed: E10.5, EN9.1
unnamed: 3V3_LED4.1, R49.2
unnamed: D23.A, R49.1
unnamed: R50.2, VIN_LED4.1
unnamed: D25.A, R50.1
unnamed: D22.C, R48.1, U13.5, VE4.2
unnamed: J61.A5, R51.2
unnamed: J61.B5, R52.2
unnamed: BT6.+, D26.A, R53.1
unnamed: JP6.3, R55.2
unnamed: JP6.1, R54.2
unnamed: E11.5, EN12.1
unnamed: E12.5, EN11.1
unnamed: 3V3_LED5.1, R59.2
unnamed: D28.A, R59.1
unnamed: R60.2, VIN_LED5.1
unnamed: D30.A, R60.1
unnamed: D27.C, R58.1, U16.5, VE5.2
PWM0: J4.32, J8.3
PWM1: J18.3, J23.32
PWM1/CAM_VDD: J4.47, J8.4, U3.3
PWM1/CAM_VDD1: J18.4, J23.47, U6.3
PWM1/CAM_VDD2: J30.4, J35.47, U9.3
PWM1/CAM_VDD3: J42.4, J47.47, U12.3
PWM1/CAM_VDD4: J54.4, J59.47, U15.3
PWM1/CAM_VDD5: J66.4, J71.47, U18.3
PWM2: J30.3, J35.32
PWM3: J42.3, J47.32
PWM4: J54.3, J59.32
PWM5: J66.3, J71.32
RTC_3V: D3.3, D6.C, J4.72, R8.2
RTC_3V1: D5.C, D9.3, J23.72, R13.2
RTC_3V2: D11.C, D14.3, J35.72, R23.2
RTC_3V3: D16.C, D19.3, J47.72, R33.2
RTC_3V4: D21.C, D24.3, J59.72, R43.2
RTC_3V5: D26.C, D29.3, J71.72, R53.2
RX1: J4.19, J6.2
RX2: J21.2, J23.19
RX3: J33.2, J35.19
RX4: J45.2, J47.19
RX5: J57.2, J59.19
RX6: J69.2, J71.19
SPI_!CS!: J4.55, J11.CS/DAT3
SPI_!CS!1: J20.CS/DAT3, J23.55
SPI_!CS!2: J32.CS/DAT3, J35.55
SPI_!CS!3: J44.CS/DAT3, J47.55
SPI_!CS!4: J56.CS/DAT3, J59.55
SPI_!CS!5: J68.CS/DAT3, J71.55
SPI_CIPO: J4.61, J5.3, J11.DO/DAT0
SPI_CIPO1: J17.3, J20.DO/DAT0, J23.61
SPI_CIPO2: J29.3, J32.DO/DAT0, J35.61
SPI_CIPO3: J41.3, J44.DO/DAT0, J47.61
SPI_CIPO4: J53.3, J56.DO/DAT0, J59.61
SPI_CIPO5: J65.3, J68.DO/DAT0, J71.61
SPI_COPI: J4.59, J5.2, J11.DI/CMD
SPI_COPI1: J17.2, J20.DI/CMD, J23.59
SPI_COPI2: J29.2, J32.DI/CMD, J35.59
SPI_COPI3: J41.2, J44.DI/CMD, J47.59
SPI_COPI4: J53.2, J56.DI/CMD, J59.59
SPI_COPI5: J65.2, J68.DI/CMD, J71.59
SPI_SCK: J4.57, J5.1, J11.SCLK
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

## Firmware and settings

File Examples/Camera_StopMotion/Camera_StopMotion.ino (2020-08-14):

/*
  Saving camera stills over UART on SparkFun Edge board
  By: Owen Lyke
  SparkFun Electronics
  Date: November 18th 2019
  This example code is in the public domain

  SparkFun labored with love to create this code. Feel like supporting open source hardware?
  Buy a board from SparkFun! https://www.sparkfun.com/products/15170

  This example shows how to use the HM01B0 camera. It will stream frames captured by the
  camera over the UART.

  To see images:
  1. upload this sketch (using baud 460800 is recommended)
  2. navigate to the library folder (~/.../Arduino/libraries/SparkFun_Himax_HM01B0_Camera)
  3. run the command 'python3 utils/Example1_StopMotion.py -b 500000 -p COM_PORT (COM_PORT is the same as the port used for upload in Arduino)
  4. say "cheese"
*/

#include "hm01b0_arduino.h"
#include "String.h"

///////////////////
// Begin User Setup

#define BAUD_RATE   460800
#define BAUD_RATE   500000

//#define DEMO_HM01B0_TEST_MODE_ENABLE          // Uncomment to enable test pattern generation
//#define DEMO_HM01B0_FRAMEBUFFER_DUMP_ENABLE   // Uncomment to enable frame output
#define DEMO_HM01B0_PYTHON                    // Uncomment to use Python script to visualize data
// (go to the sketch directory and use 'python3 utils/Example1_StopMotion.py -p {COM_PORT}'

// End User Setup
/////////////////

HM01B0 myCamera;            // Declare an HM01B0 object called 'myCamera'
// The camera will try to specialize for the host architecture
// however it will fall back to a slow generic interface if no
// specialization is available.
// The default is not guaranteed to work due to the high amount
// of data the camera needs to transfer


// Auto-configure for python if requested
#ifdef DEMO_HM01B0_PYTHON
#define DEMO_HM01B0_FRAMEBUFFER_DUMP_ENABLE
#undef  DEMO_HM01B0_TEST_MODE_ENABLE
#endif // DEMO_HM01B0_PYTHON

// Forward declarations
void printWord(uint32_t num);
void printByte(uint8_t num);

void setup() {

  // Start up serial monitor
  Serial.begin(BAUD_RATE);
  do {
    delay(500);
  } while (!Serial);
  Serial.println();
  Serial.println("Camera stop motion");

  //  // Turn on camera regulator if using Edge board
  //#if defined (ARDUINO_SFE_EDGE)
  //  pinMode(AM_BSP_GPIO_CAMERA_HM01B0_DVDDEN, OUTPUT);
  //  digitalWrite(AM_BSP_GPIO_CAMERA_HM01B0_DVDDEN, HIGH);
  //  Serial.println("Turned on Edge camera regulator");
  //#endif
  pinMode(PWM1, OUTPUT);
  digitalWrite(PWM1, HIGH); //Turn camera on

  //pinMode(D1, OUTPUT);

  // Start the camera
  if (myCamera.begin() != HM01B0_ERR_OK) {
    Serial.print("Camera.begin() failed with code: " + String(myCamera.status) + ". Consider re-seating the camera.\n");
  } else {
    Serial.print("Camera started successfully\n");
  }

  // Calibrate Autoexposure
//  Serial.println("Calibrating Auto Exposure...");
//  myCamera.calibrateAutoExposure();
//  if (myCamera.status != HM01B0_ERR_OK) {
//    Serial.println("\tnot converged");
//  } else {
//    Serial.println("\tconverged!");
//  }

#ifdef DEMO_HM01B0_TEST_MODE_ENABLE
  // Enable test mode (generates a 'walking 1s' pattern to verify interface function
  Serial.print("Enabling test mode...\n");
  myCamera.enableTestMode();
  if (myCamera.status != HM01B0_ERR_OK) {
    Serial.print("\tfailed\n");
  } else {
    Serial.print("\tsucceeded!\n");
  }

  // In test mode capturing a frame fills the buffer with the test pattern
  myCamera.capture();

  uint32_t mismatches = myCamera.countTestMismatches();
  Serial.print("Self-test mismatches: 0x");
  printWord(mismatches);
  Serial.print("\n");
#endif

  Serial.write(0x55);                                                    // Special character to sync Python script
  Serial.print("\n\n");                                                  // Newlines allow Python script to find frame start
}

void loop() {
  // Take an image
  myCamera.capture();

#ifdef DEMO_HM01B0_FRAMEBUFFER_DUMP_ENABLE
  // Print out a frame for the Python script to pick up
  framebuffer_dump();
#else
  // Print auto exposure state
  Serial.print("AE convergance(0x");
  printByte(myCamera.aeConvergenceStatus);
  Serial.print(") TargetMean 0x");
  printByte(myCamera.aecfg.ui8AETargetMean);
  Serial.print(", ConvergeInTh 0x");
  printByte(myCamera.aecfg.ui8ConvergeInTh);
  Serial.print(", AEMean 0x");
  printByte(myCamera.aecfg.ui8AEMean);
  Serial.print("\n");
#endif

  // Wait a second
  //delay(1000);
}

//
// Utility functions

// hex formating
// Thanks to bootsector on the Arduino forums:
// https://forum.arduino.cc/index.php?topic=38107.msg282336#msg282336
void printWord(uint32_t num) {
  char tmp[9];                  // 8 hex digits + null terminator
  sprintf(tmp, "%08X", num);
  Serial.print(tmp);
}

void printByte(uint8_t num) {
  char tmp[3];                  // 2 hex digits + null terminator
  sprintf(tmp, "%02X", num);
  Serial.print(tmp);
}

// frame buffer dump (formatted for python script)
void framebuffer_dump( void ) {
  Serial.print("+++ frame +++");                                         // Mark frame start
  for (uint32_t ui32Idx = 0; ui32Idx < myCamera.frameBufferSize; ui32Idx++) { // Process all bytes in frame
    if ((ui32Idx & 0xF) == 0x00) {                                            // Print address every 16 bytes
      Serial.print("\n0x");
      printWord(ui32Idx);
      Serial.print(" ");
    }
    printByte(myCamera.frameBuffer[ui32Idx]);                                 // Print byte value
    Serial.print(" ");
  }
  Serial.print("\n--- frame ---\n");
  memset(myCamera.frameBuffer, 0x00, sizeof(myCamera.frameBufferSize));       // Zero out frame buffer for help identifying errors
}

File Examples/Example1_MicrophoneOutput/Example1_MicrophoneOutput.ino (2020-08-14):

/* Author: Nathan Seidle
  Created: July 24, 2019
  License: MIT. See SparkFun Arduino Apollo3 Project for more information

  This example demonstrates how to use the pulse density microphone (PDM) on Artemis boards.
  This library and example are heavily based on the Apollo3 pdm_fft example.
*/

//Global variables needed for PDM library
#define pdmDataBufferSize 4096 //Default is array of 4096 * 32bit
uint16_t pdmDataBuffer[pdmDataBufferSize];

//Global variables needed for the FFT in this sketch
float g_fPDMTimeDomain[pdmDataBufferSize * 2];
float g_fPDMFrequencyDomain[pdmDataBufferSize * 2];
float g_fPDMMagnitudes[pdmDataBufferSize * 2];
uint32_t sampleFreq;

//Enable these defines for additional debug printing
#define PRINT_PDM_DATA 0
#define PRINT_FFT_DATA 0

#include <PDM.h> //Include PDM library included with the Aruino_Apollo3 core
AP3_PDM myPDM;   //Create instance of PDM class

//Math library needed for FFT
#define ARM_MATH_CM4
#include <arm_math.h>

void setup()
{
  Serial.begin(115200);
  Serial.println("SparkFun PDM Example");

  if (myPDM.begin(36, 37) == false) // Turn on PDM with default settings, start interrupts
  {
    Serial.println("PDM Init failed. Are you sure these pins are PDM capable?");
    while (1)
      ;
  }
  Serial.println("PDM Initialized");

  printPDMConfig();
}

void loop()
{
  if (myPDM.available())
  {
    myPDM.getData(pdmDataBuffer, pdmDataBufferSize);

    printLoudest();
  }

  // Go to Deep Sleep until the PDM ISR or other ISR wakes us.
  am_hal_sysctrl_sleep(AM_HAL_SYSCTRL_SLEEP_DEEP);
}

//*****************************************************************************
//
// Analyze and print frequency data.
//
//*****************************************************************************
void printLoudest(void)
{
  float fMaxValue;
  uint32_t ui32MaxIndex;
  int16_t *pi16PDMData = (int16_t *)pdmDataBuffer;
  uint32_t ui32LoudestFrequency;

  //
  // Convert the PDM samples to floats, and arrange them in the format
  // required by the FFT function.
  //
  for (uint32_t i = 0; i < pdmDataBufferSize; i++)
  {
    if (PRINT_PDM_DATA)
    {
      Serial.printf("%d\n", pi16PDMData[i]);
    }

    g_fPDMTimeDomain[2 * i] = pi16PDMData[i] / 1.0;
    g_fPDMTimeDomain[2 * i + 1] = 0.0;
  }

  if (PRINT_PDM_DATA)
  {
    Serial.printf("END\n");
  }

  //
  // Perform the FFT.
  //
  arm_cfft_radix4_instance_f32 S;
  arm_cfft_radix4_init_f32(&S, pdmDataBufferSize, 0, 1);
  arm_cfft_radix4_f32(&S, g_fPDMTimeDomain);
  arm_cmplx_mag_f32(g_fPDMTimeDomain, g_fPDMMagnitudes, pdmDataBufferSize);

  if (PRINT_FFT_DATA)
  {
    for (uint32_t i = 0; i < pdmDataBufferSize / 2; i++)
    {
      Serial.printf("%f\n", g_fPDMMagnitudes[i]);
    }

    Serial.printf("END\n");
  }

  //
  // Find the frequency bin with the largest magnitude.
  //
  arm_max_f32(g_fPDMMagnitudes, pdmDataBufferSize / 2, &fMaxValue, &ui32MaxIndex);

  ui32LoudestFrequency = (sampleFreq * ui32MaxIndex) / pdmDataBufferSize;

  if (PRINT_FFT_DATA)
  {
    Serial.printf("Loudest frequency bin: %d\n", ui32MaxIndex);
  }

  Serial.printf("Loudest frequency: %d         \n", ui32LoudestFrequency);
}

//*****************************************************************************
//
// Print PDM configuration data.
//
//*****************************************************************************
void printPDMConfig(void)
{
  uint32_t PDMClk;
  uint32_t MClkDiv;
  float frequencyUnits;

  //
  // Read the config structure to figure out what our internal clock is set
  // to.
  //
  switch (myPDM.getClockDivider())
  {
  case AM_HAL_PDM_MCLKDIV_4:
    MClkDiv = 4;
    break;
  case AM_HAL_PDM_MCLKDIV_3:
    MClkDiv = 3;
    break;
  case AM_HAL_PDM_MCLKDIV_2:
    MClkDiv = 2;
    break;
  case AM_HAL_PDM_MCLKDIV_1:
    MClkDiv = 1;
    break;

  default:
    MClkDiv = 0;
  }

  switch (myPDM.getClockSpeed())
  {
  case AM_HAL_PDM_CLK_12MHZ:
    PDMClk = 12000000;
    break;
  case AM_HAL_PDM_CLK_6MHZ:
    PDMClk = 6000000;
    break;
  case AM_HAL_PDM_CLK_3MHZ:
    PDMClk = 3000000;
    break;
  case AM_HAL_PDM_CLK_1_5MHZ:
    PDMClk = 1500000;
    break;
  case AM_HAL_PDM_CLK_750KHZ:
    PDMClk = 750000;
    break;
  case AM_HAL_PDM_CLK_375KHZ:
    PDMClk = 375000;
    break;
  case AM_HAL_PDM_CLK_187KHZ:
    PDMClk = 187000;
    break;

  default:
    PDMClk = 0;
  }

  //
  // Record the effective sample frequency. We'll need it later to print the
  // loudest frequency from the sample.
  //
  sampleFreq = (PDMClk / (MClkDiv * 2 * myPDM.getDecimationRate()));

  frequencyUnits = (float)sampleFreq / (float)pdmDataBufferSize;

  Serial.printf("Settings:\n");
  Serial.printf("PDM Clock (Hz):         %12d\n", PDMClk);
  Serial.printf("Decimation Rate:        %12d\n", myPDM.getDecimationRate());
  Serial.printf("Effective Sample Freq.: %12d\n", sampleFreq);
  Serial.printf("FFT Length:             %12d\n\n", pdmDataBufferSize);
  Serial.printf("FFT Resolution: %15.3f Hz\n", frequencyUnits);
}

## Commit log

2020-04-07 Update MM connector. Remove backup files. Add ignore.
    [MachineLearning-MM-Carrier.brd, MachineLearning-MM-Carrier.sch]
2020-04-23 v11 routed
    [MachineLearning-MM-Carrier.brd, MachineLearning-MM-Carrier.sch]
2020-04-27 Change RTC charge to 3.3k. Add bulk cap to vreg output.
    [MachineLearning-MM-Carrier.brd, MachineLearning-MM-Carrier.sch]
2020-05-04 Update micromod connector to new SPI pinout
    [MachineLearning-MM-Carrier.brd, MachineLearning-MM-Carrier.sch]
2020-05-04 Fix route to SPI SCK
    [MachineLearning-MM-Carrier.brd, MachineLearning-MM-Carrier.sch]
2020-05-05 Update v-reg device
    [MachineLearning-MM-Carrier.brd, MachineLearning-MM-Carrier.sch]
2020-08-14 Re-route camera connector for face up. Convert buzzard labels. Add power control to camera regulator.
    [MachineLearning-MM-Carrier-Panel.GBL, MachineLearning-MM-Carrier-Panel.GBO, MachineLearning-MM-Carrier-Panel.GBS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]
2020-08-14 Remove old test file
    [MachineLearning-MM-Carrier-Panel.brd]
2020-09-10 Update MicroMod connector with SPI port changes
    [MachineLearning-MM-Carrier.brd, MachineLearning-MM-Carrier.sch]
2020-09-10 Rename SPI lines for clarification
    [MachineLearning-MM-Carrier.brd, MachineLearning-MM-Carrier.sch]
2020-09-10 Update production files to v13
    [MachineLearning-MM-Carrier-Panel.brd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]
2022-05-27 Update schematic with correct 0x24 camera I2C address
    [MachineLearning-MM-Carrier.sch]

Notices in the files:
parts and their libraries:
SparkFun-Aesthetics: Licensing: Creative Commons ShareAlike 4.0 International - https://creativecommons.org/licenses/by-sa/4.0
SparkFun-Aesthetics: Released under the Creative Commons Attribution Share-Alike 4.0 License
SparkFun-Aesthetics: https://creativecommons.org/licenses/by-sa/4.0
